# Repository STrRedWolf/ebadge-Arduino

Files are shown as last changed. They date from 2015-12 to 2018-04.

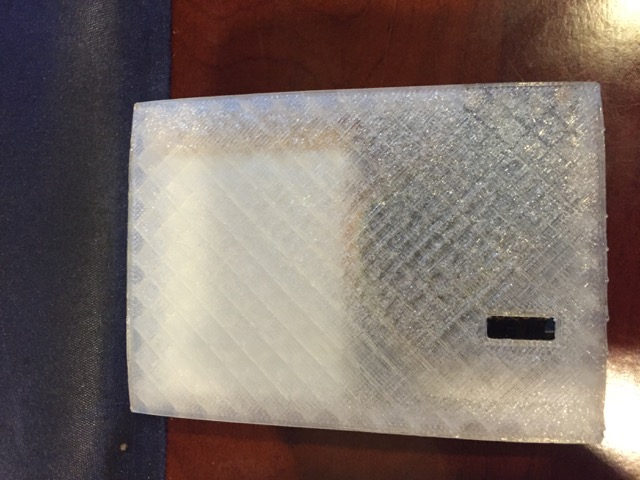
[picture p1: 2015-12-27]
images/IMG_0418.jpg

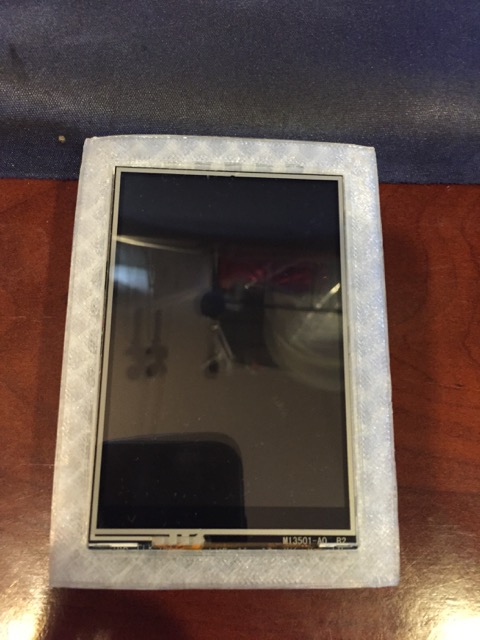
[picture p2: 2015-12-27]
images/IMG_0416.jpg

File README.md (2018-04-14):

# ebadge-Arduino
An electronic badge using Adafruit parts!  It's a 3.5" screen that rotates through TGA (previously TGA) images stored on a 1GB MicroSD card.

Around November 1st, 2017, Adafruit released a 3.5" TFT Feather wing, which simplifies things, and makes it all accessible!

# New version (mark 3 and 4)

## Bill of Materials

Get all of these from Adafruit!

* 3.5" TFT Feather wing
* Feather M0 Basic Proto
* LithIon battery.  The mark 3 version will fit a PKCELL ICR18650 2200mAh 3.7V cell (barrel shape).  The mark 4 uses a PKCELL flat-pack 2500mAh 3.7V cell.
* A small capacity (8 GB is fine) MicroSD card, FAT16 formatted.
* A 3D printer (of course -- I used a Printrbot Simple Metal)
* Breadboard friendly SPDT slide switch
* Wire, of course. (the silicon coated wire may be best. I used the 22awg wire I had.)
* Heat-shrink tubing

You'll also need some Scotch tape.

## Building it!

Print out the parts first.  If you have the round battery, you'll have to print the mark 3 version (EBadge3-*.stl).  Flat battery is the mark 4 design (EBadge4-*.stl).  The TFT goes right in and is pressure fit with the back half.  Mark 3's will need to use the divot to keep the switch in place.

You will need to solder two wires to the switch (middle pin and one of the side pins) first.  Then solder one wire to the Enable Pad, the other to the Ground pad. Snip the unused pin on the switch.  Make sure the Enable switch on the TFT is switched ON, and the switch itself is switched to connect the two wired pins.  Afterwards, bend the metal that forms the short sides of the switch out so they're flush with the switch (we'll use these to keep the switch from moving).

Solder up the M0 with the shipped headers.  

From here, it depends on which version you have.

### Mark 3 (barrel battery)

Plug in the battery, and plug it in the back of the TFT.  I route the cable of the battery under the M0 Feather. 

Slide the switch into it's place and follow it up with the "divot" you printed.  You did print the divot, right?

Now close up the two halves and you should be ready for programming it.

### Mark 4 (flat battery)

Take the Feather M0 you soldered up, and trim all the pins under the board to be flush with the plastic spacer the pins were shipped with.  When they're all done, remove the spacer.  The length of the pins fits on top of the TFT's connector, making it rather flush.

Connect the battery and tape it to the back shell you printed, all the way up top. The raised part at the bottom corner (where the USB port is) lays on top of the switch, so you should place the battery catty-cornered from it.

Place the switch in the top shell.  You may find it easier to tape the switch in place.

Now close up the two halves and you should be ready for programming it.

## Program it!

Plug it in, turn it on, and upload the sketch.  

Now prep your MicroSD card!

# Old version (mark 1)

## Bill of Materials (old version)

* Adafruit Feather 32u4 Basic Proto
* 3.5" TFT 320x480 + Touchscreen Breakout Board w/MicroSD socket (HXD8357D)
* LithIon battery, 3.7v 2000mAh
* Breadboard friendly SPDT slide switch.
* Female/female jumper wires, 3"
* 22awg wire (I used the hook-up wire set)
* Hot glue gun w/glue
* Male right-angle break-away header, 0.1" pitch
* A 1 GB MicroSD card, FAT16 formatted.

## Soldering the Feather's headers and the switch

The first photo in the images directory gives an idea on how to solder things.  The switch is soldered on the back and centered with the Feather.  A six-pin header is soldered starting at pin 13 and going to pin 6 (which in the end will leave pin 9 "floating").  Two individual headers are covering all but a hole for the ground and 3.3V that stretches along the sides of the Feather.  A wire goes from a ground to the switch and then to the Enable pin.  A three-pin header is soldered on "backwards" on the SPI pins to keep it compact.

# Prepping the MicroSD card:  Truevision TGA (Targa) files.

The eBadge as it's coded now will **NOT** take BMPs.  

Previously, I elected to use a much simplier format called Portable PixMap, or PPM.  This is a Unix-borne format, but most software (including Gimp) will export to "binary PPM".  PPM has a simple header and then data right after it, making the code much simpler.  For details, go to NetPBM's site.

As of v0.3, we can now read uncompressed TGA files.  IrfanView converts to this format, and Gimp will save to this format in both regular (flipped) and unflipped versions.  The code handles both.

Resize the files at 320px wide, 480px tall files, and name each one starting with 0001.TGA all the way up to 0255.TGA.  Put them on the root of the MicroSD card.

# Longevity

+----------+-------------------------------+
| Revision | Time                          |
+----------+-------------------------------+
| Mark 3   | 10 hours (roughly)
| Mark 4   | 11+ hours (was stopped early) |
+----------+-------------------------------+

# Ideas for expansion

* Hidden 80x30 column VT52 terminal?
* Micro BBS?

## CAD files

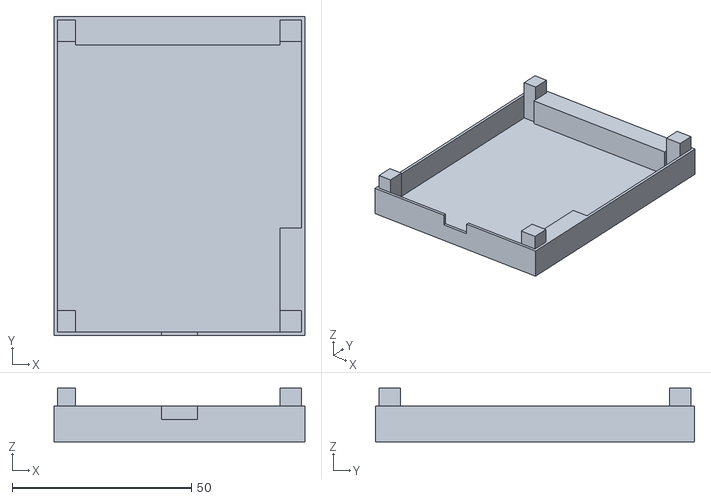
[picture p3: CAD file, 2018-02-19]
STL/EBadge4-back.stl
70.0 x 89.0 x 15.0

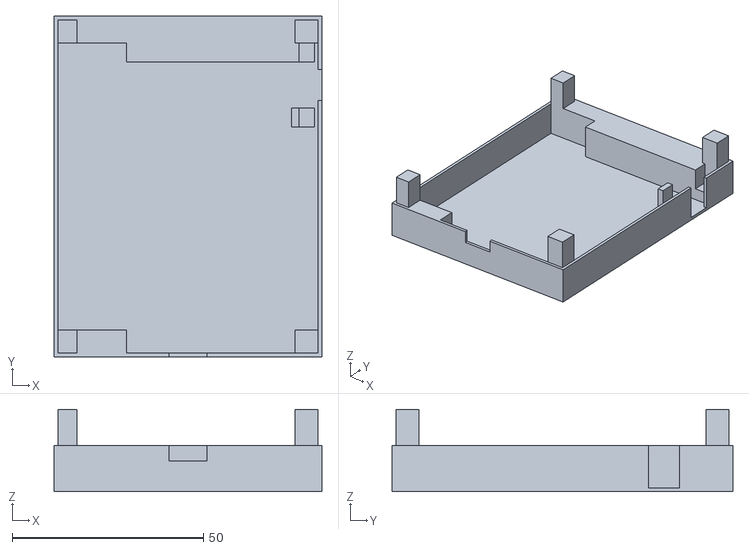
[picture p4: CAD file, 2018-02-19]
STL/EBadge3-back.stl
70.0 x 89.0 x 21.5

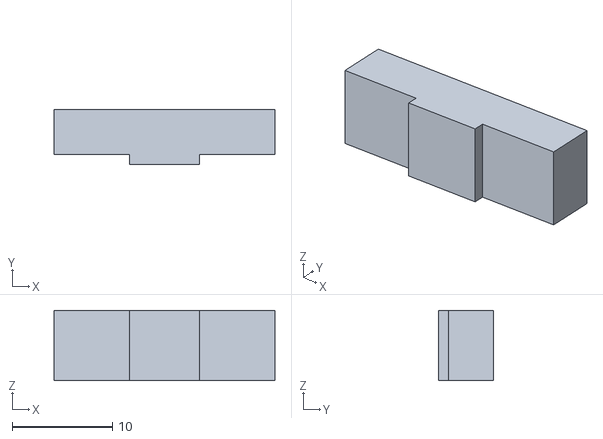
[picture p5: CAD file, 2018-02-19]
STL/EBadge3-divot.stl
22.0 x 5.50 x 7.00

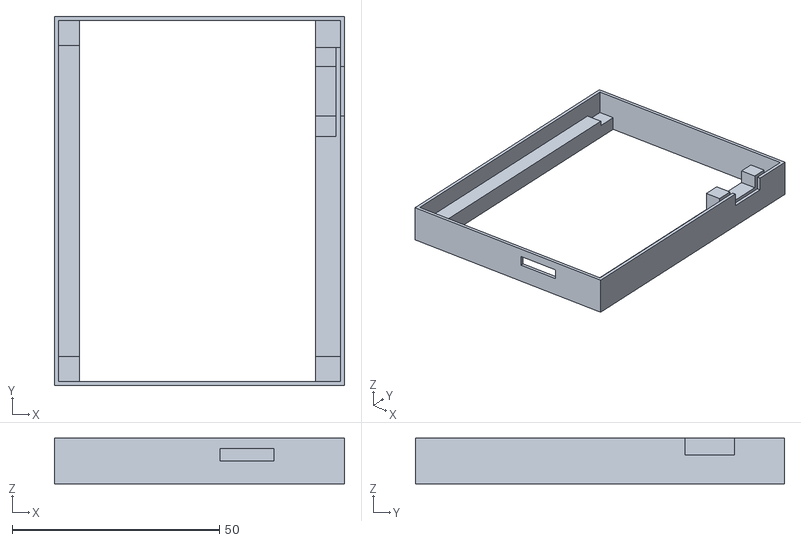
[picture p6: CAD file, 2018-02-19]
STL/EBadge4-front.stl
70.0 x 89.0 x 11.0

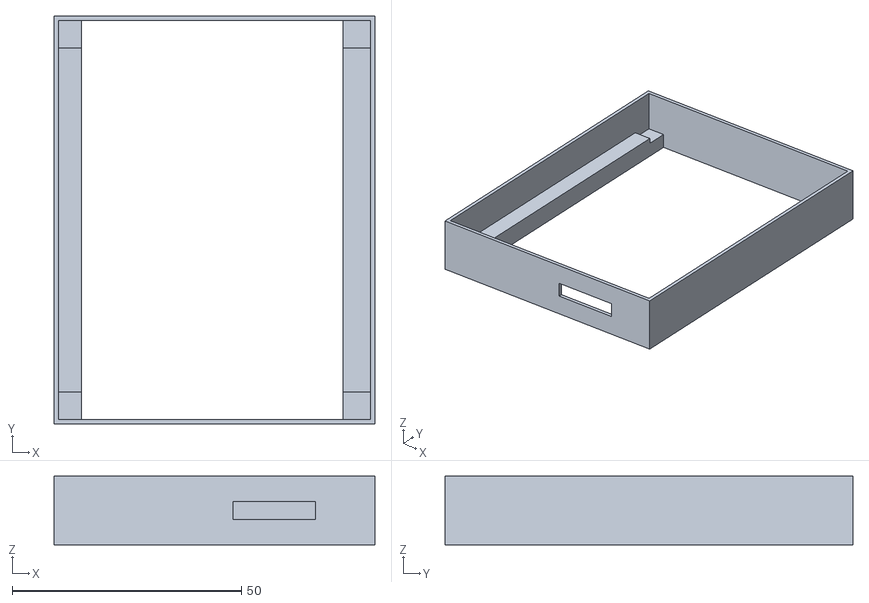
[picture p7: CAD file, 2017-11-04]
STL/EBadge2-front.stl
70.0 x 89.0 x 15.0

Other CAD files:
STL/EBadge2-back.stl
Sketchup_sources/EBadge1-back.skp
Sketchup_sources/EBadge1-front.skp
Sketchup_sources/EBadge2-back.skp
Sketchup_sources/EBadge2-front.skp
Sketchup_sources/EBadge3-back.skp
Sketchup_sources/EBadge3-divot.skp
Sketchup_sources/EBadge4-back.skp
Sketchup_sources/EBadge4-front.skp

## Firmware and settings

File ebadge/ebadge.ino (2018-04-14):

/* Ebadge v0.3 by Kelly "STrRedWolf" Price
 *
 * Based on Adafruit's Bitmap example code.
 *
 * This is licensed via the MIT license per below.
 */

/* v0.3: TGA support */

/***************************************************
  This is our Bitmap drawing example for the Adafruit HX8357 Breakout
  ----> http://www.adafruit.com/products/2050

  Check out the links above for our tutorials and wiring diagrams
  These displays use SPI to communicate, 4 or 5 pins are required to
  interface (RST is optional)
  Adafruit invests time and resources providing this open source code,
  please support Adafruit and open-source hardware by purchasing
  products from Adafruit!

  Written by Limor Fried/Ladyada for Adafruit Industries.
  MIT license, all text above must be included in any redistribution
 ****************************************************/


#include <Adafruit_GFX.h>    // Core graphics library
#include "Adafruit_HX8357.h"
#include <SPI.h>
#include <SD.h>

// TFT display and SD card will share the hardware SPI interface.
// Hardware SPI pins are specific to the Arduino board type and
// cannot be remapped to alternate pins.  For Arduino Uno,
// Duemilanove, etc., pin 11 = MOSI, pin 12 = MISO, pin 13 = SCK.

#define HARDSPI 1

#ifdef HARDSPI
// Hardware SPI that's not aliased anywhere (like the Feather)
// On the Feather M0:
#define TFT_DC 10
#define TFT_CS 9
#define TFT_RST -1
#define SD_CS 5
#define LITEPIN 0

#else
// Uno/Duemilanove/Pro Mini multifunction pins.
#define TFT_DC 2
#define TFT_CS 10
#define TFT_RST -1
#define SD_CS 7
#define LITEPIN 0

#endif

Adafruit_HX8357 tft = Adafruit_HX8357(TFT_CS, TFT_DC, TFT_RST);

// We need this set here.
int fileindex = 1;
uint8_t opmode=0;

void setup(void) {
  Serial.begin(9600);

  tft.begin(HX8357D);
  tft.setRotation(2); // upsidedown
  tft.fillScreen(HX8357_BLUE);

  if(LITEPIN != 0) {
    pinMode(LITEPIN,OUTPUT);
    analogWrite(LITEPIN,191);
  }
  
  tft.print(F("Initializing SD card... "));
  if (!SD.begin(SD_CS)) {
    tft.fillScreen(HX8357_RED);
    tft.println(F("failed!"));
    opmode++;
  }
  tft.println(F("OK!"));
}

void loop(void) {
  tft.println(F("In the loop..."));
  showpic();
}

void showpic() {
  char fi;
  char fname[16] = "0000.TGA";
  
  fi=(char)(fileindex & 255);

  //tft.println(fname);

  if( (fi/100) > 0) {
    fname[1]=(char)(fi/100)+'0';
    fi=fi%100;
  }
  //tft.println(fname);

  if((fi/10) > 0) {
    fname[2]=(char)(fi/10)+'0';
    fi=fi%10;
  }
  //tft.println(fname);
  //tft.print(F("bug"));
  fname[3]=((char)(fi & 15)+'0');

  tft.println(fname);

  if(tgaDraw(fname) == 0)
  {
    delay(30000);
    fileindex++;
  } else {
    fileindex=1;
  }
  //opmode++;
}

// This function opens a NetPBM Pixmap (ppm) file and
// displays it at 0,0.  It's sped up
// by reading many pixels worth of data at a time
// (rather than pixel by pixel).  Increasing the buffer
// size takes more of the Arduino's precious RAM but
// makes loading a little faster.  20 pixels seems a
// good balance.

// With the M0's, do whole lines.
#define BUFFPIXEL 80

uint8_t ppmDraw(char *filename) {

  File     ppmFile;
  int      maxVal;
  uint32_t ppmImageoffset = 0;
  uint8_t  sdbuffer[3*BUFFPIXEL]; // pixel buffer (R+G+B per pixel)
  uint8_t  buffidx = sizeof(sdbuffer); // Current position in sdbuffer
  int      w, h, row, col, berr;
  uint8_t  r, g, b;
  uint32_t pos = 0, startTime = millis();

  tft.print(F("Loading image "));
  tft.println(filename);

  // Open requested file on SD card
  if ((ppmFile = SD.open(filename)) == NULL) {
    //Serial.print(F("File not found: "));
    //Serial.println(filename);
    tft.print(F("File not found: "));
    tft.println(filename);
    return 0;
  }

  tft.println(F("Opened..."));

  // Parse the PPM header.
  // The format is roughly "P6 X Y Z" followed by a hard LF and raw RGB
  // X is width, Y is height, Z is a max value.
  // Spaces above are whitespace (what isspace() says it is)
  // A "# comment" can occur before the hard LF and raw RGB.

  // Is it a P6?
  if(ppmFile.read() != 0x50 && ppmFile.read() != 0x36)
  {
      // Nope.
      tft.print(F("File not a P6 PPM: "));
      tft.println(filename);
    return 1;
  }
  w=readNum(ppmFile);
  
  w=readNum(ppmFile);
  h=readNum(ppmFile);
  maxVal=readNum(ppmFile);
  ppmImageoffset=ppmFile.position();  

//  tft.println(F("Ready to plot."));
  
  //tft.setAddrWindow(0, 0, 319, 479);

  berr=-1;
  for (row=0; row<h; row++) { // For each scanline...
    for (col=0; col<w; col++) { // For each pixel...
      // Time to read more pixel data?
      if (buffidx >= sizeof(sdbuffer)) { // Indeed
        berr=ppmFile.read(sdbuffer, sizeof(sdbuffer));
        if(berr==-1) break;
        buffidx = 0; // Set index to beginning
      }
      // Convert pixel from ppm to TFT format, push to display
      r = sdbuffer[buffidx++];
      g = sdbuffer[buffidx++];
      b = sdbuffer[buffidx++];
      
      //tft.pushColor(tft.color565(r,g,b));
      tft.drawPixel(col,row,tft.color565(r,g,b));
    } // end pixel
    // delay(10);
  } // end scanline
  
  ppmFile.close();
  return 1;
}

int readNum(File &f) {
  boolean junk=true;
  int num = 0;

  // Clean up beforehand.
  while(junk) {
    // Chew up any whitespace preceding.
    while(isWhitespace(f.peek())) {
        f.read();
    }
    
    // Comment?  Skip that as well
    if(f.peek() == '#') {
       while(f.peek() != 10) {
          f.read();
       }
       f.read(); // Chew the linefeed as well.
    } else {
      junk=false;
    }
  }
  
  // Now read the number.
  while(isDigit(f.peek())) {
      f.peek();
    num=(num*10)+(f.read() - '0');
  }

  // Be kind, and chomp any whitespace up to a next LF.
  while(isWhitespace(f.peek()) && f.peek() != 10) {
	f.read();
  }
  if(f.peek() == 10)
	f.read();

  return num;
}

// Mini-BBS mode.
void bbs() {
  ;
}

uint8_t tgaDraw(char *filename) {
    File f;
    uint8_t  idlen,cmaptype,imgtype,cmapentrysize,depth,info;
    uint16_t  cmapfirst,cmaplen,xorg,yorg,w,h,row,col,r,g,b;
    uint8_t sdbuffer[256]; // generic buffer.
    int sx,sy,x,y,dx,dy;
    int isok=0;
    
    //tft.setCursor(0,0);
    tft.println(filename);
    
    // Open the file...
    if((f = SD.open(filename)) == NULL) {
        tft.println(F("File not found"));
        return 1;
    }
    
    // Pull the header, and parse through it a bit.
    idlen=f.read();
    if((cmaptype=f.read()) > 1) {
        tft.println(F("File has an invalid format."));
        return 2;
    }
    
    imgtype=f.read();
    cmapfirst=f.read()+(f.read() << 8);
    cmaplen=f.read()+(f.read() << 8);
    cmapentrysize=f.read();
    xorg=f.read()+(f.read() << 8);
    yorg=f.read()+(f.read() << 8);
    w=f.read()+(f.read() << 8);
    h=f.read()+(f.read() << 8);
    depth=f.read();
    info=f.read();
    
    // Before we go futher, lets save ourselves
    // and limit what we *can* read.
    // 24-bit true-color, 240x320, top-left corner is 0,0
    // direction left to right, then top to bottom.
    if(depth != 24 || (imgtype & 15) != 2) {
        tft.println(F("File is an unsupported format."));
        return 3;
    }
    
    if(w != 320 || h != 480) {
        tft.print(F("File is not 320 by 480: "));
        tft.print(w);
        tft.print("x");
        tft.println(h);
        return 4;
    }

    if(xorg == 0 && yorg == 0 && (info & 0x30)==0) {
      // image is flipped
      sx=0;
      sy=479;
      dx=1;
      dy=-1;
      isok=1;
    }

    if(xorg == 0 && yorg == 479 && (info&0x30)==0x20) {
      sx=sy=0;
      dx=dy=1;
      isok=1;
    }
    
    if(isok ==0) { // 479
        tft.print(F("File is stored weird. Org/info:"));
        tft.print(xorg);
        tft.print(",");
        tft.print(yorg);
        tft.print(" ");
        tft.println(info);
        return 5;
    }
        
    // Skip the info...
    if(idlen > 0) {
        f.read(sdbuffer,idlen);
    }
    
    // There shouldn't be any cmap data...
    if(cmaplen > 0) {
        tft.println(F("File has invalid format."));
        return 2;
    }
    
    // Now we can get the image data.
    y=sy;
    for(row=0;row<480;row++) {
      x=sx;
        for(col=0;col<320;col++) {
            f.read(sdbuffer,3);

            // TGA uses BGR.
            b=sdbuffer[0];
            g=sdbuffer[1];
            r=sdbuffer[2];
            tft.drawPixel(x,y,tft.color565(r,g,b));
            x+=dx;
        }
        delay(10); //because the screen can't cope.
        y+=dy;
    }
    
    // we're done
    f.close();
    return 0;
}
       

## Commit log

2015-12-27 Full upload, ready to go.
    [EBadge1-back.skp, EBadge1-front.skp]
2017-11-04 Update for Featherwings
    [EBadge1-back.skp, EBadge1-front.skp, EBadge2-back.skp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]
2018-02-19 Update Mark 3 case, add Mark 4.
    [EBadge3-back.skp, EBadge3-back.stl, EBadge3-divot.skp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]
